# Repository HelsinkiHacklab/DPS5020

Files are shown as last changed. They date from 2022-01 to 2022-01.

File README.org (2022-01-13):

*  DPS5020 virtalähdekotelo
:PROPERTIES:
:TOC:      :include all
:END:

DPS5020 teholähteen kotelon tiedostojen tallennusrepositorio. Kotelon
dokumentaatio https://wiki.helsinki.hacklab.fi/DPS5020_kotelo

* Ohjeet kotelo.dxf tekemiseen

- Exportoi Fusion 360:stä stl-tiedostot
  - body 'Kotelo' -> Save Mesh virtalähde-kotelo-vXXX.stl
  - body 'Kansi' -> Save Mesh virtalähde-kansi-vXXX.stl
- Muunna [[https://github.com/tjltjl/plycutter][plycutter]]:lla stl tiedostot dxf-tiedostoiksi
  - ~plycutter -o virtalähde-kotelo.dxf --thickness=3 virtalähde-kotelo-vXXX.stl~
  - ~plycutter -o virtalähde-kansi.dxf --thickness=3 virtalähde-kotelo-vXXX.stl~
- Yhdistä librecad:ssä dxf-tiedostot ja muokkaa ulkoreunojen ja sisäreunojen värit
  - yhdistä ~virtalähde-kotelo.dxf~ ja ~virtalähde-kansi.dxf~ tiedostoon ~kotelo-osat.dxf~
  - muokkaa ~kotelo.dxf~
    - aseta väri kotelon osien ulkoreunojen väri:  modify -> attribute -> red 
    - aseta väri kotelon osien sisäreunojen väri:  modify -> attribute -> cyan
- kotelon osat asettelu aihioon ~deepnest~ -työkalulla
  - import ~kotelo-osat.dxf~
  - lisää suorakaide 20 x 20 cm ja merkkaa se "sheet"
  - käynnistä deepnest operaatio ja odota, että kotelon osat pakkautuvat siististi
  - export ~kotelo.dxf~
- talleta  ~kotelo.dxf~ github:iin [[file:kotelo.dxf]]

* Muutoslogi

|       Pvm | Muutos                 | Suunnitelman versio |
|-----------+------------------------+---------------------|
| 13.1.2022 | DC-liitin, ohjeistusta | [[file:TODO.org::#DPS5020_V2][DPS5020_V2]]          |

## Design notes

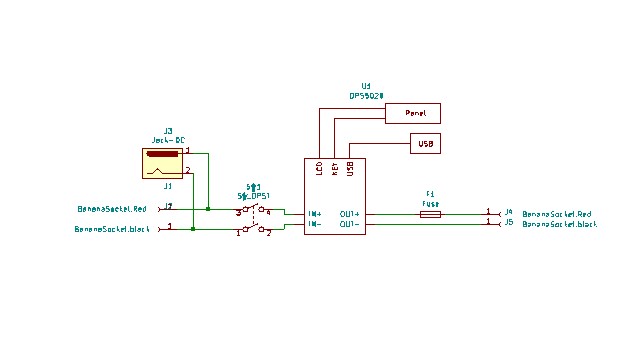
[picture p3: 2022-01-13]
pics/kytkenta.jpg

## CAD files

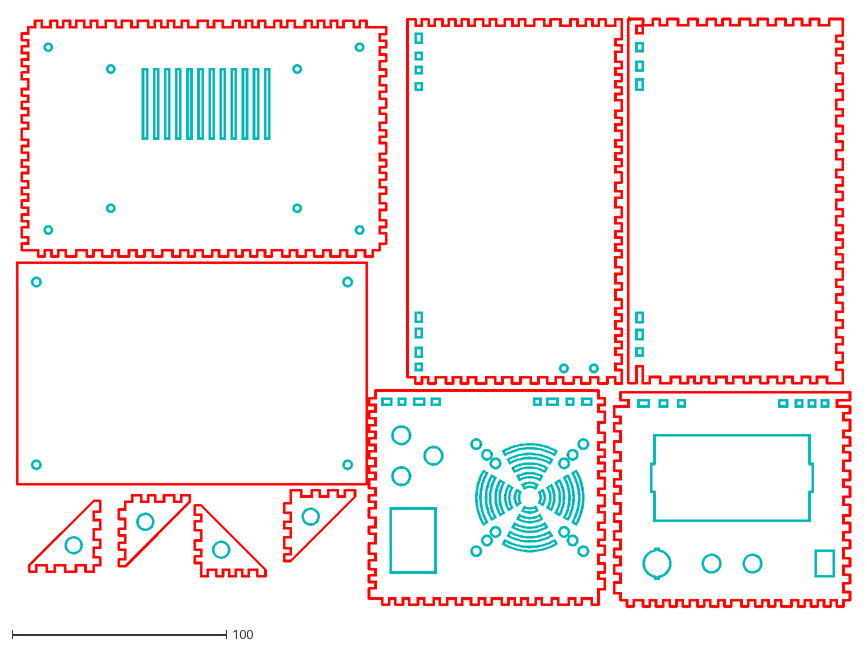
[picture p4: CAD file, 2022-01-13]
kotelo.dxf
389.8 x 276.0

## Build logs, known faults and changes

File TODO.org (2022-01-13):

* Muutokset

** dps5020_v2
   :PROPERTIES:
   :CUSTOM_ID: DPS5020_v2
   :END:

- [X] Kotelon muutokset
  - [X] Kotelon takaseinään 8mm reikä DC liitintä varten
  - [X] Kotelon takaseinä virtakytkinmen aukon suurennus 21x30mm
  - [X] github päivitys
    - [X] kotelo.dxf
    - [X] kansi.dxf poistetaa
- [-] BOM lisäykset/muutos wikissä
  - [ ] Feature DC-liitin lisää
  - [ ] Feature: kytkin asennusaukko 21x30mm koko
  - [X] DC runkoliitin 5.5mm/2.5mm
  - [X] DC liittimen kytkentää varten Abiko haarukka 4.3 mm, +2 kpl
  - [X] virtakytkin: asennusaukko 21x30mm +(13mmx19mm)+ 
  - [ ] sulake, T (hidas), 5x20mm
  - [X] Materiaalit
    - [X] Kutistesukkaa
    - [X] 2.5mm2 johtoa
    - [X] 1.5mm2 johtoa
- [X] Materiaalinhankinta
  - [X] kotelo.dxf (pakattu dxf) 28 x 39 cm => 5 x 2 * (0,28 x 0,39) = 1.40  x 0.78 m
  - [X] akryylilevy 2.05 x 1.52 m, josta leikataan 0.82 m x 1.52 m
- [-] Wiki ohjeet
  - [ ] Linkki skeemaan: file:pics/schema.png
  - [ ] Suositus juottaa Abiko liittimet ja suojata ne kutistesukalla
  - [ ] DC-runkoliittimen juotoskorvat ovat ahtaat, mukana 1.5mm2 johto 
  - [ ] Ehdotus käyttää PC virtalähdettä ja huomio, että PC
    virtalähteiden DC liittimet eivät ole standardoituja -> Paketin DC liitin
    kannattaa vaihtaa virtalähteeseen sopivaan
  - [X] poista github linkki katto.dxf
  - [X] Poltto-ohjeet
    - [X] import kotelo.dxf
    - [X] disable muut värit paitsi sisäviivat (cyan) && leikkaus
    - [X] disable muut värit paitsi reunaviivat (read) && leikkaus
    - [X] vinkit
      - [X] värien leikkausjärjestyksen vaihdossa värit muuttuvat ->
        ei suositella (käytä disable)
- [X] github README.org:
  - [X] toimitusprosessi kuvaus
    - [X] Fusion Body -> Save Mesh
    - [X] plycutter
    - [X] libreCad
      - [X] edit: reunaviivat red
      - [X] edit: sisäviivat cyan
    - [X] deepnest
      - [X] import kotelo && kansi
      - [X] deepnest
      - [X] export kotelo.dxf

** v97
   :PROPERTIES:
   :CUSTOM_ID: v97
   :END:

- [X] naparuuvien läpivienti nyt 7.5 mm, pitää olla > 8mm (--> 8.3mm)
- [X] USB aukko
  - [X] nyt 6x12 --> 8.5x12
  - [X] siirto sisäänpäin 1mm, 
- [X] kansi
  - [X] 0.2 mm kapeammaksi
  - [X] n. 0.3 mm syvemmälle

** Versio i (initial)
   :PROPERTIES:
   :CUSTOM_ID: i
   :END:

- naparuuvien läpivienti nyt 7.5 mm, pitää olla > 8mm (--> 8.5mm)                    
- USB aukko 8.5x11.5, vasen sisäreuna lisää +2.5mm, korotus = siirto
  sisäänpäin 1mm
- kansi 0.2 mm kapeammaksi, n. 0.3 mm syvemmälle
